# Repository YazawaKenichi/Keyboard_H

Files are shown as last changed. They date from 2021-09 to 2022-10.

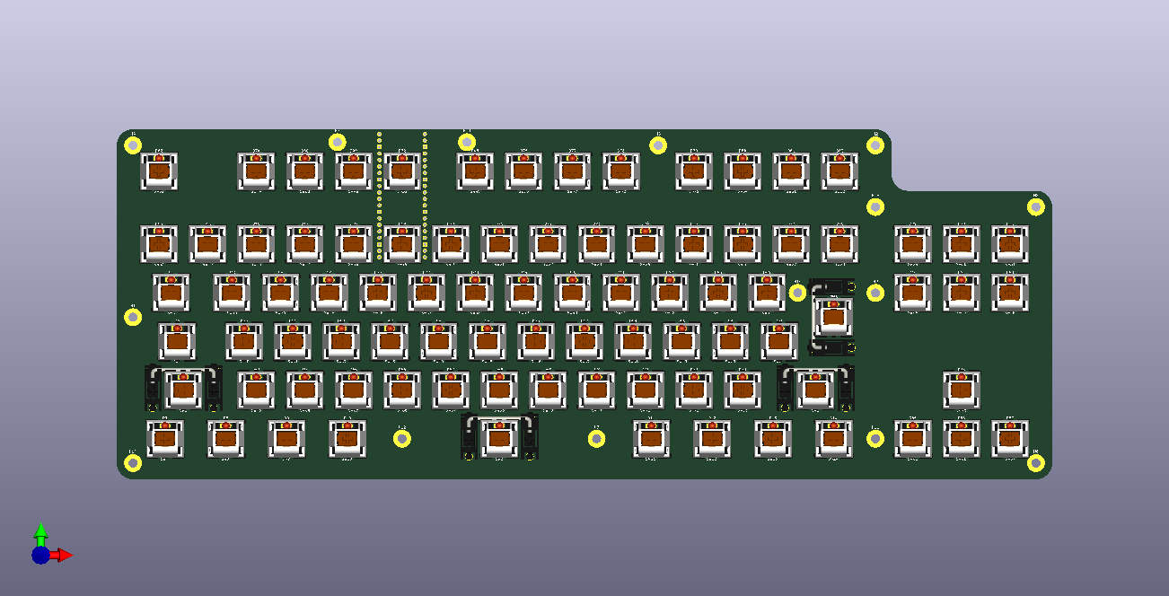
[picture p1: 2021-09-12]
pcb/3D_model/png/keyboard_h.png

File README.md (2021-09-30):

# Keyboard_H
This is My First Keyboard Project.

#### 基板とシャーシのデータの完全形
これらのデータで発注・加工する。

#### 自作キーボードの設計
このリポジトリは自作キーボードのためのリポジトリ。
ただしハードウェア設計に関するファイルのみ。うｐ主のインフラの事情的に、ハードは Windows ソフトは Ubuntu で開発することになってしまったので、ハードとソフトでリポジトリを分けた。
統合してぇなぁ...

### 以下全部自己満メモ！自分用れどめ！

##### LED の点灯回路について考える
- USB バスパワー:5V 500mA
- Raspberry Pi Pico の GPIO のパワー
- Raspberry Pi Pico のピンによる電気特性は [RP2040 のデータシート](https://datasheets.raspberrypi.org/rp2040/rp2040-datasheet.pdf) 『5.2.3. Pin Specifications』を参照
- .
- キーボード全体で 300mA になるようにしたい。
- USB 5V だが、実際 500 mA くらい使用すると 4.8V くらいに下がってしまうので、USB デバイスはそうならないように余裕を持たせて設計する。
- GPIO で FET のゲートを制御し、Vbus からの電力を供給する。
- LED と制限抵抗は必ず一つにまとめる。
- .
- 謎があって、USB から電力を入手するとしても、87 個の LED を並列に点灯させようとすると、一つの 抵抗 + LED に流せる電流は最大でも 300 mA / 87 個 ≒ 3.4 mA となってちょっと弱すぎじゃね？って感じがしてしまう。これじゃあ LED 点灯できないじゃん...
- .
- LED のデータシート？これ何？
- output current 出力の最大値 MAX 100 mA
- current limit 制限電流 MIN 150 mA TYP 350 mA MAX 450 mA
- .
- LED の設定
- 一つの LED に電流制限可変抵抗と LED を直列に繋いだ回路において、デューティー比 100% という条件で以下の状態を記録。
- 電源電圧 5 V
- 抵抗降下電圧 1.692 V
- LED 電圧 3.17 V
- 電流 19.30 mA
- 抵抗値 84.5 Ω
- ※小数点以下一桁目より下は当てにならないかも... 0.1 レベルなら当てになるかも。
- 上記が丁度よい輝度になっている。
- .
- 参考までに、電源電圧 3.3 V の時の値も記録しておく。
- 抵抗降下電圧 0.267 V
- LED 電圧 3.03 V
- 電流 10.58 mA
- 抵抗値 21.2 Ω
- ※小数点以下一桁目より下はry
- .
- ついでのついでに参考として、データシートの値を記録しておく。
- デューティー比 100% 電流値  30 mA
- デューティー比 10 % 電流値 100 mA
- 20 mA の時の LED 電圧降下 3.1 V
- .
- 疑問点
- PWM 制御すれば、デューティー比 100 % の時よりも大きな電流を流せるということはわかるけど、推奨デューティー比が 1/10 とかになってて、結局欲しい輝度に届かなくなったりしないのかな？
- Arduino でいいから実験してみると良いかもしれない。
- .
- FET + PWM で実験してみた。
- Nch MOSFET 2N7000 で実験したので、回路的にはローサイド駆動。
- 電流制限抵抗 45Ω PWM: 20ms(50Hz) 100% において、以下を記録。
- 電流 30 mA LED 降下電圧 3.5 V 抵抗降下電圧 1.46 V 但し、100% では僅かに発熱したため、100% 以下での駆動を推奨する。
- .
- なんかもうぐちゃぐちゃしてきたから、いっそのこと実験して特性曲線を自分でプロットすればいいんじゃないかと思って、特性曲線を描いてみた。いや、厳密には点を打っていっただけなんだけど...
- そのスプレッドシートが[こちら](https://docs.google.com/spreadsheets/d/14N7y58BiVdMig64xLq-WeDRAnExjTIeJXDbpEm-JDAk/edit?usp=sharing)
- .
- PWM 制御について参考にしたサイトと数式（自作）
- [PWM について考える基礎](https://www.sist.ac.jp/club/mcf/Umeta_lecture/PWM.html)
- [上記サイト内で出てくる数式](https://www.geogebra.org/m/sed2b5tw) y が電力 x が電流 r が制限抵抗 v が電源電圧。回路は 電源-抵抗-対象素子-GND
- .
- いろいろ考えたけど、USB 電源である以上、最大 500 mA で、しかも余裕を持たせないといけないから 300 mA にしないといけないことも考慮して、一つの 抵抗-LED に流せる電流を考えたら、3.5 mA が限界なわけで、結局 3.5 mA 流すことになるならそれで考えたら良いのではないかという結論に至った。
- Vbus-可変抵抗-LED-[D]NchMOSFET(ON)-[S]GND[G]330Ωカーボン抵抗-3V3PWM の回路において、PWM 100% かつ LED 電流 3.5 の時、630Ω の電流制限抵抗がいい感じ。

##### FET のゲート抵抗について考える
- ゲート抵抗が無いと FET が ON になったときにショートしてしまう。よってゲート抵抗は必要。
- ではゲート抵抗はどのくらいが良いのか。実は計算する方法がある。
- R_G = V_in / I_G ∩ I_G = Q_g / t で求めることができる。
|記号|意味|
|---|---|
|R_G|ゲート抵抗|
|V_in|入力電圧|
|I_G|ゲート電流|
|Q_g|ゲート入力電荷量|
|t|ゲート立ち上がり時間|
- ここで、入力電圧はゲート抵抗への入力電圧であり、ゲート抵抗を超えた時のゲート電圧とは違う。（つまりゲート抵抗で電圧降下する前の電圧ということ）
- ゲート入力電荷量は、使用する FET のデータシートに記載されている。
- 2N7002 のデータシート見てみたけど、書いてない...今回は 100R でいいんじゃね？

##### 教わったこと
- LED のみを安直に並列に接続してはいけない。一つの LED に対して一つの電流制限抵抗が必要となる。よって LED を並列に接続したいときは電流制限抵抗 + LED で一つの素子として考えたほうがいいかもしれない。
- USB の電力は 5V 500 mA である。しかし、デバイスが 500 mA 近く流れそうになると実際は 5 V より少し小さい値に低下してしまう。これを防ぐためにデバイスに流れる電流は 300 mA 程度とし、余裕を持たせたほうが良い。
- FET のゲート抵抗は計算できる。
- FET の G-S 間には 10kR の抵抗をつなぐとよいことを知った。これは MOSFET が OFF の時確実にゲートを OFF にする目的。抵抗が無いと、G-S 間の疑似コンデンサに電荷がたまった状態で、電位は 0V にならず、浮遊状態となり、基準電位を失ってしまう。結果的にゲートの電位が不安定になり FET を ON にしていないにも関わらず勝手に ON になってしまうことが起きてしまう。
- USB 端子に直接つながっている Vbus 端子には、コンデンサがあるとよい。USB 機器のコードは長く、電圧が降下してしまうので、それを防ぐ意味でコンデンサを Vbus GND 間に取り付ける。ただし今回は PWM 制御することを考えるので、電気容量についても注意する必要がある。井口先輩は考えた末に「勘だけど 20 ~ 47 uF」と言っていた。
- ベタグランドはただやたらめったら面積を広くすればよいというものではなく、ベタグランドがアンテナになってしまうときは、敢えて面積を小さくしてでもベタ GND を除去する必要がある。どうしても除去したくない場合は、裏面のベタグランドにビアを繋ぐことで回避できる。
- 配線幅は電流に応じて変更したほうが良い。というかしろ。

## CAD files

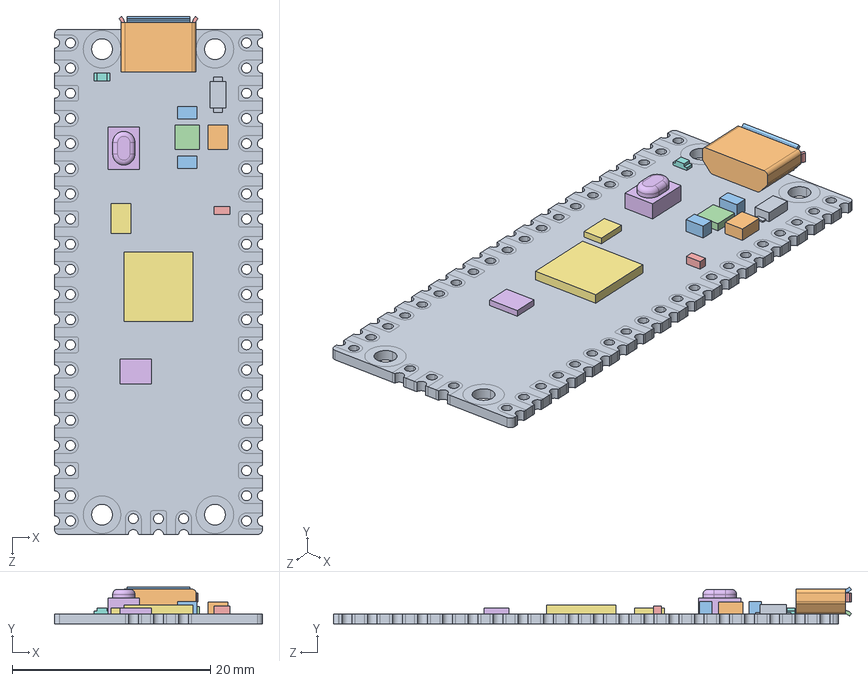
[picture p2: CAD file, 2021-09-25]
pcb/3D_model/step/Pico-R3-step/Pico-R3.step
21.0 x 3.73 x 52.3 mm
PICO_REF_BOARD.STEP
PICO_REF_USB.STEP
PICO_REF_SWITCH.STEP
PICO_REF_MICROCONTROLLER.STEP
PICO_REF_LED.STEP
PICO_REF_ONSEMI.STEP
PICO_BOURNS.STEP
PICO_MURATA.STEP x 2
PICO_RICHTEK.STEP
PICO_DIODES.STEP
PICO_AEL.STEP
PICO_WINBOND.STEP

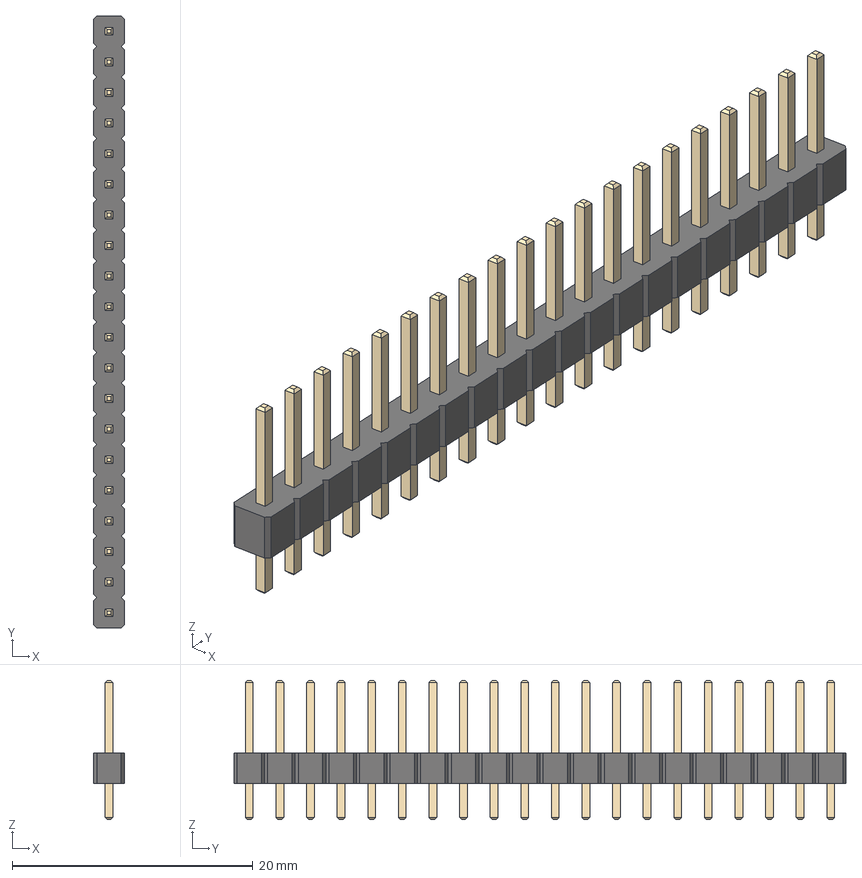
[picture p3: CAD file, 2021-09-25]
pcb/3D_model/step/PinHeader_1x20_P2.54mm_Vertical.step
2.54 x 50.8 x 11.5 mm

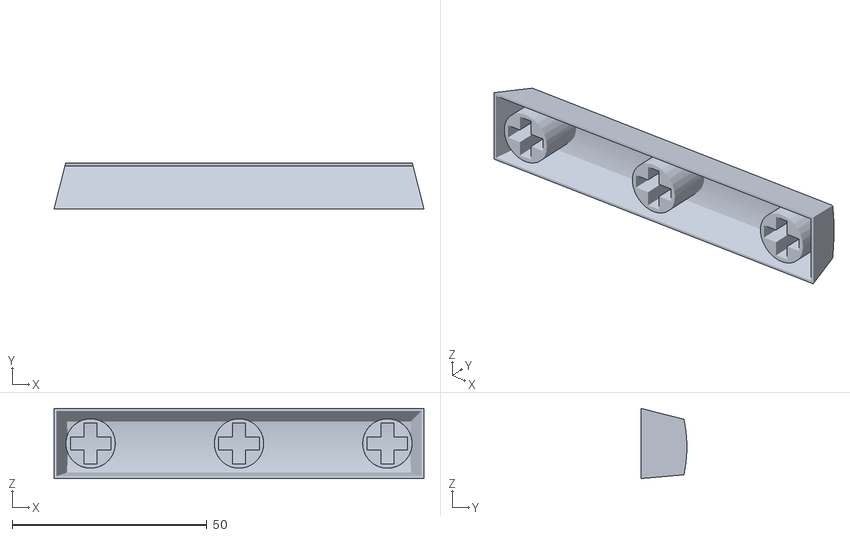
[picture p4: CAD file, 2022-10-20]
chassis/2022/SpaceKeyCap.stl
95.0 x 11.7 x 18.0

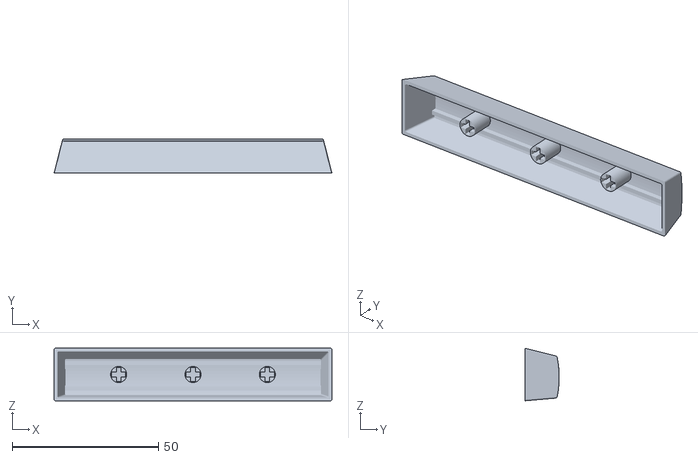
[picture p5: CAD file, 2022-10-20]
chassis/2022/SpaceKeyCap_v8.stl
95.0 x 11.8 x 18.0

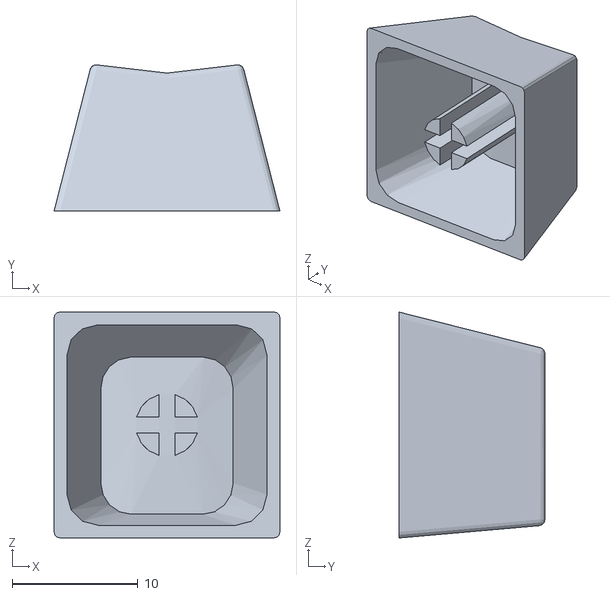
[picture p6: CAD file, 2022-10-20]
chassis/2022/now.stl
18.0 x 11.7 x 18.0

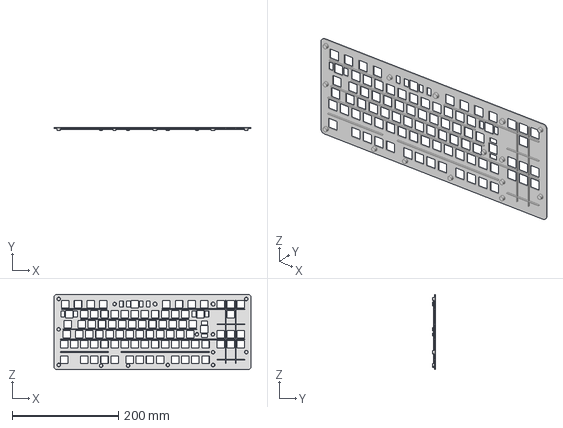
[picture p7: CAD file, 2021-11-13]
chassis/2022/Plate.step
371.5 x 5.00 x 142.2 mm

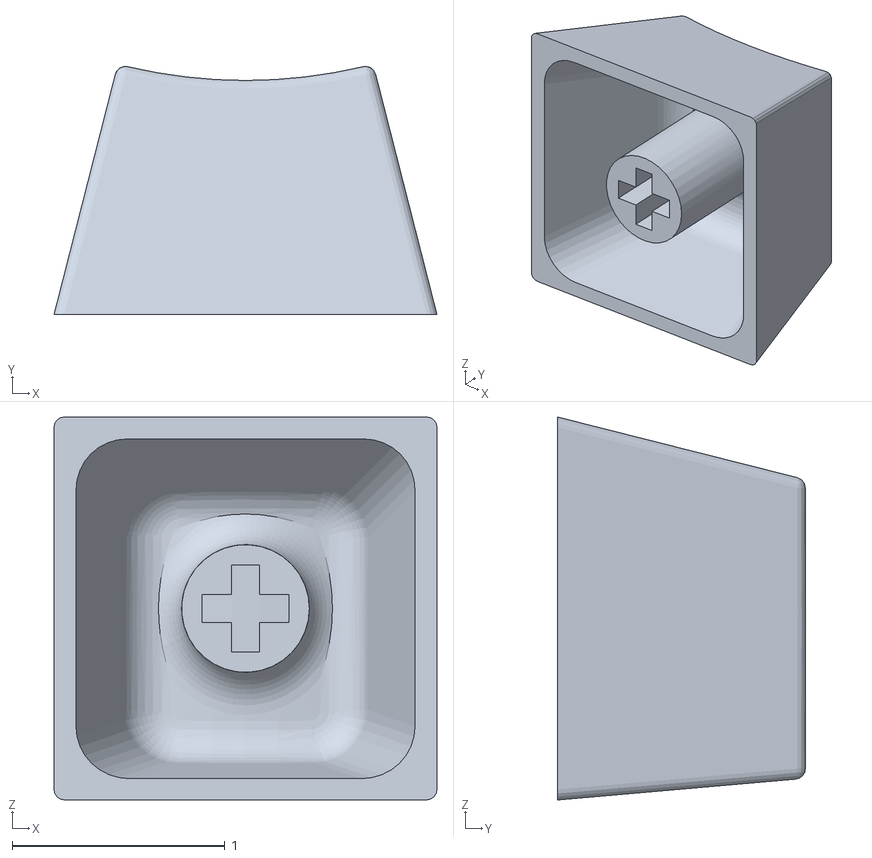
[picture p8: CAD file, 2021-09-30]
chassis/2022/Cap Plane.stl
1.80 x 1.17 x 1.80

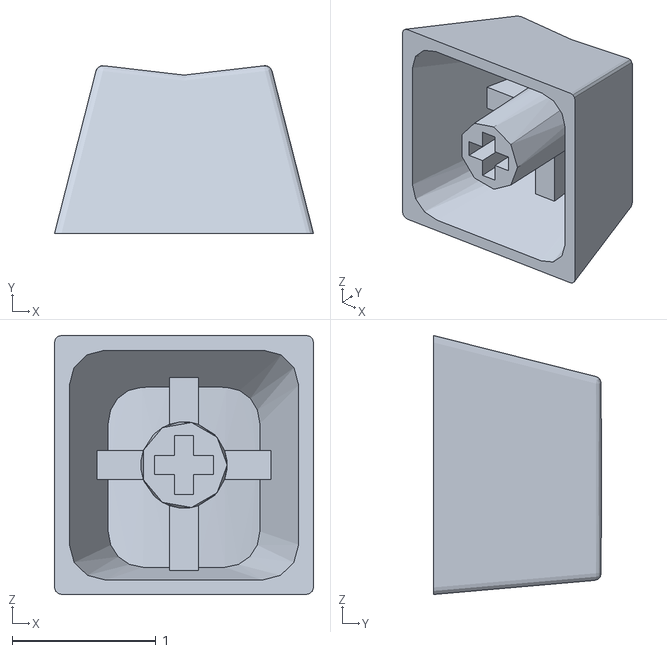
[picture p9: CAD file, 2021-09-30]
chassis/2022/Cap Support.stl
1.80 x 1.17 x 1.80

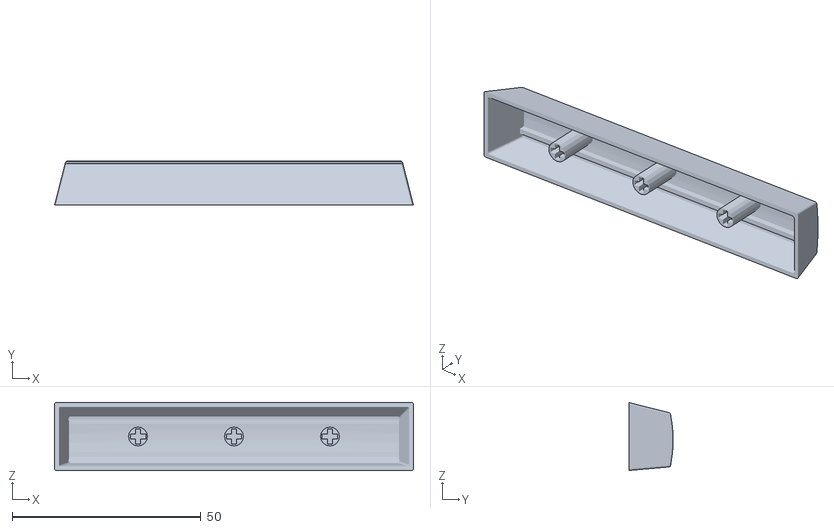
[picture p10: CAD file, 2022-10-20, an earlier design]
chassis/2022/SpaceKeyCap_v4.stl
95.0 x 11.8 x 18.0

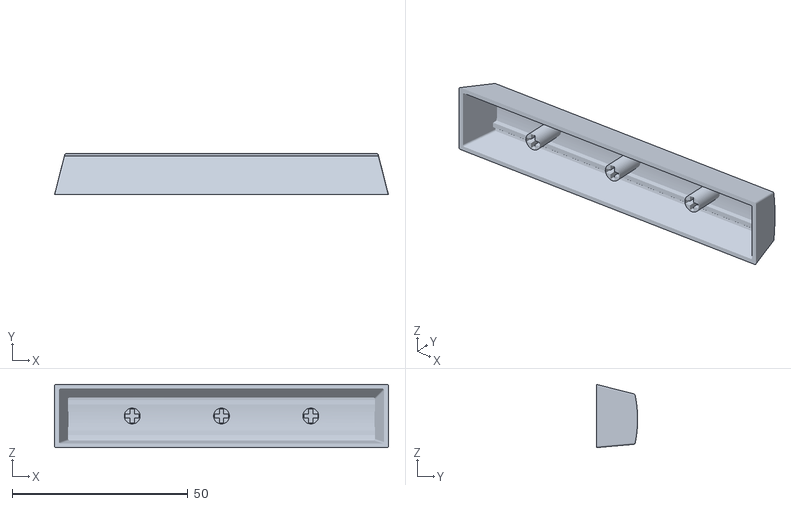
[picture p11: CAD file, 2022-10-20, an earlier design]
chassis/2022/SpaceKeyCap_v9_Stereolithography.stl
95.0 x 11.8 x 18.0

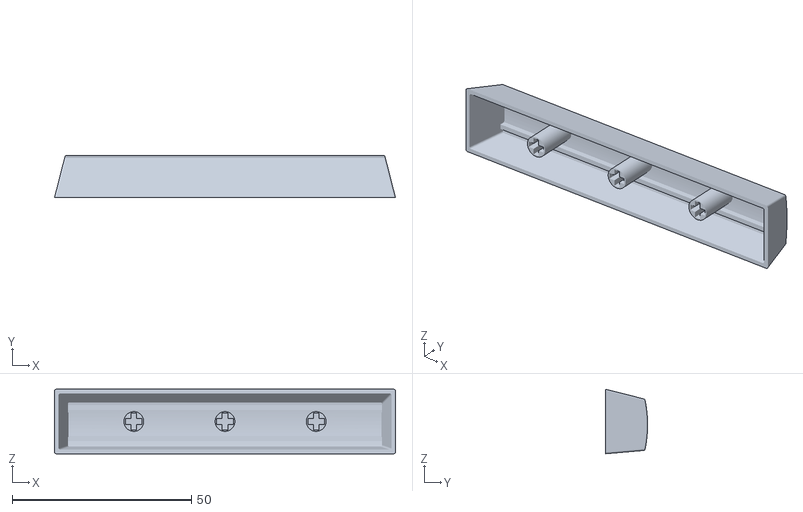
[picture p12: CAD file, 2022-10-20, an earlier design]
chassis/2022/SpaceKeyCap_v7.stl
95.0 x 11.8 x 18.0

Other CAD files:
chassis/2022/SpaceKeyCap_v10_Stereolithography.stl
chassis/2022/SpaceKeyCap_v5.stl
chassis/2022/SpaceKeyCap_v6.stl
chassis/2022/SpaceKeyCap_v3.stl
chassis/2022/SpaceKeyCap_v2.stl
chassis/2020/Base.x_t
chassis/2020/Plate.x_t
chassis/2022/Assembly.iam
chassis/2022/Base.idw
chassis/2022/Base.ipt
chassis/2022/Cap.ipt
chassis/2022/OldVersions/Assembly.0016.iam
chassis/2022/OldVersions/Base.0001.idw
chassis/2022/OldVersions/Base.0042.ipt
chassis/2022/OldVersions/Cap.0009.ipt
chassis/2022/OldVersions/Plate.0004.idw
chassis/2022/OldVersions/Plate.0043.ipt
chassis/2022/OldVersions/SpaceKeyCap.0002.idw
chassis/2022/OldVersions/SpaceKeyCap.0009.ipt
chassis/2022/OldVersions/stabbar_u5.0001.ipt
chassis/2022/Plate.idw
chassis/2022/Plate.ipt
chassis/2022/SpaceKeyCap.idw
chassis/2022/SpaceKeyCap.ipt
chassis/2022/stabbar_u5.ipt
chassis/Plate.ipt
pcb/3D_model/step/COMPOUND.ipt
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

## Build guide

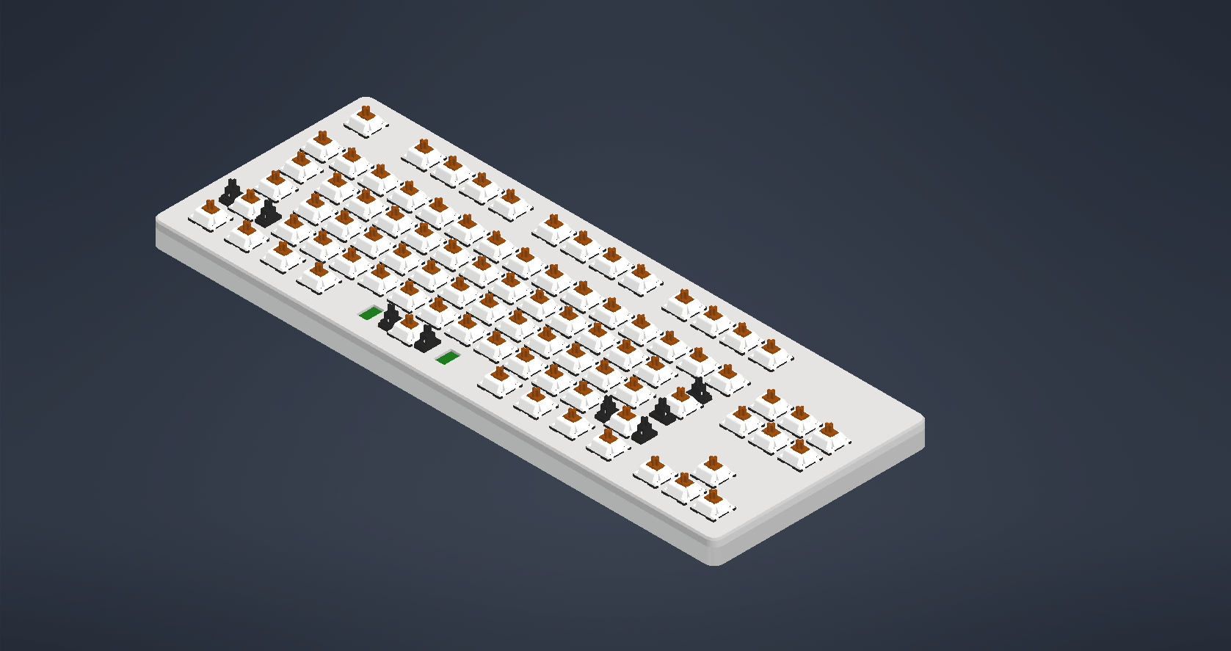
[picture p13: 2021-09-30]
chassis/2022/Assembly.png

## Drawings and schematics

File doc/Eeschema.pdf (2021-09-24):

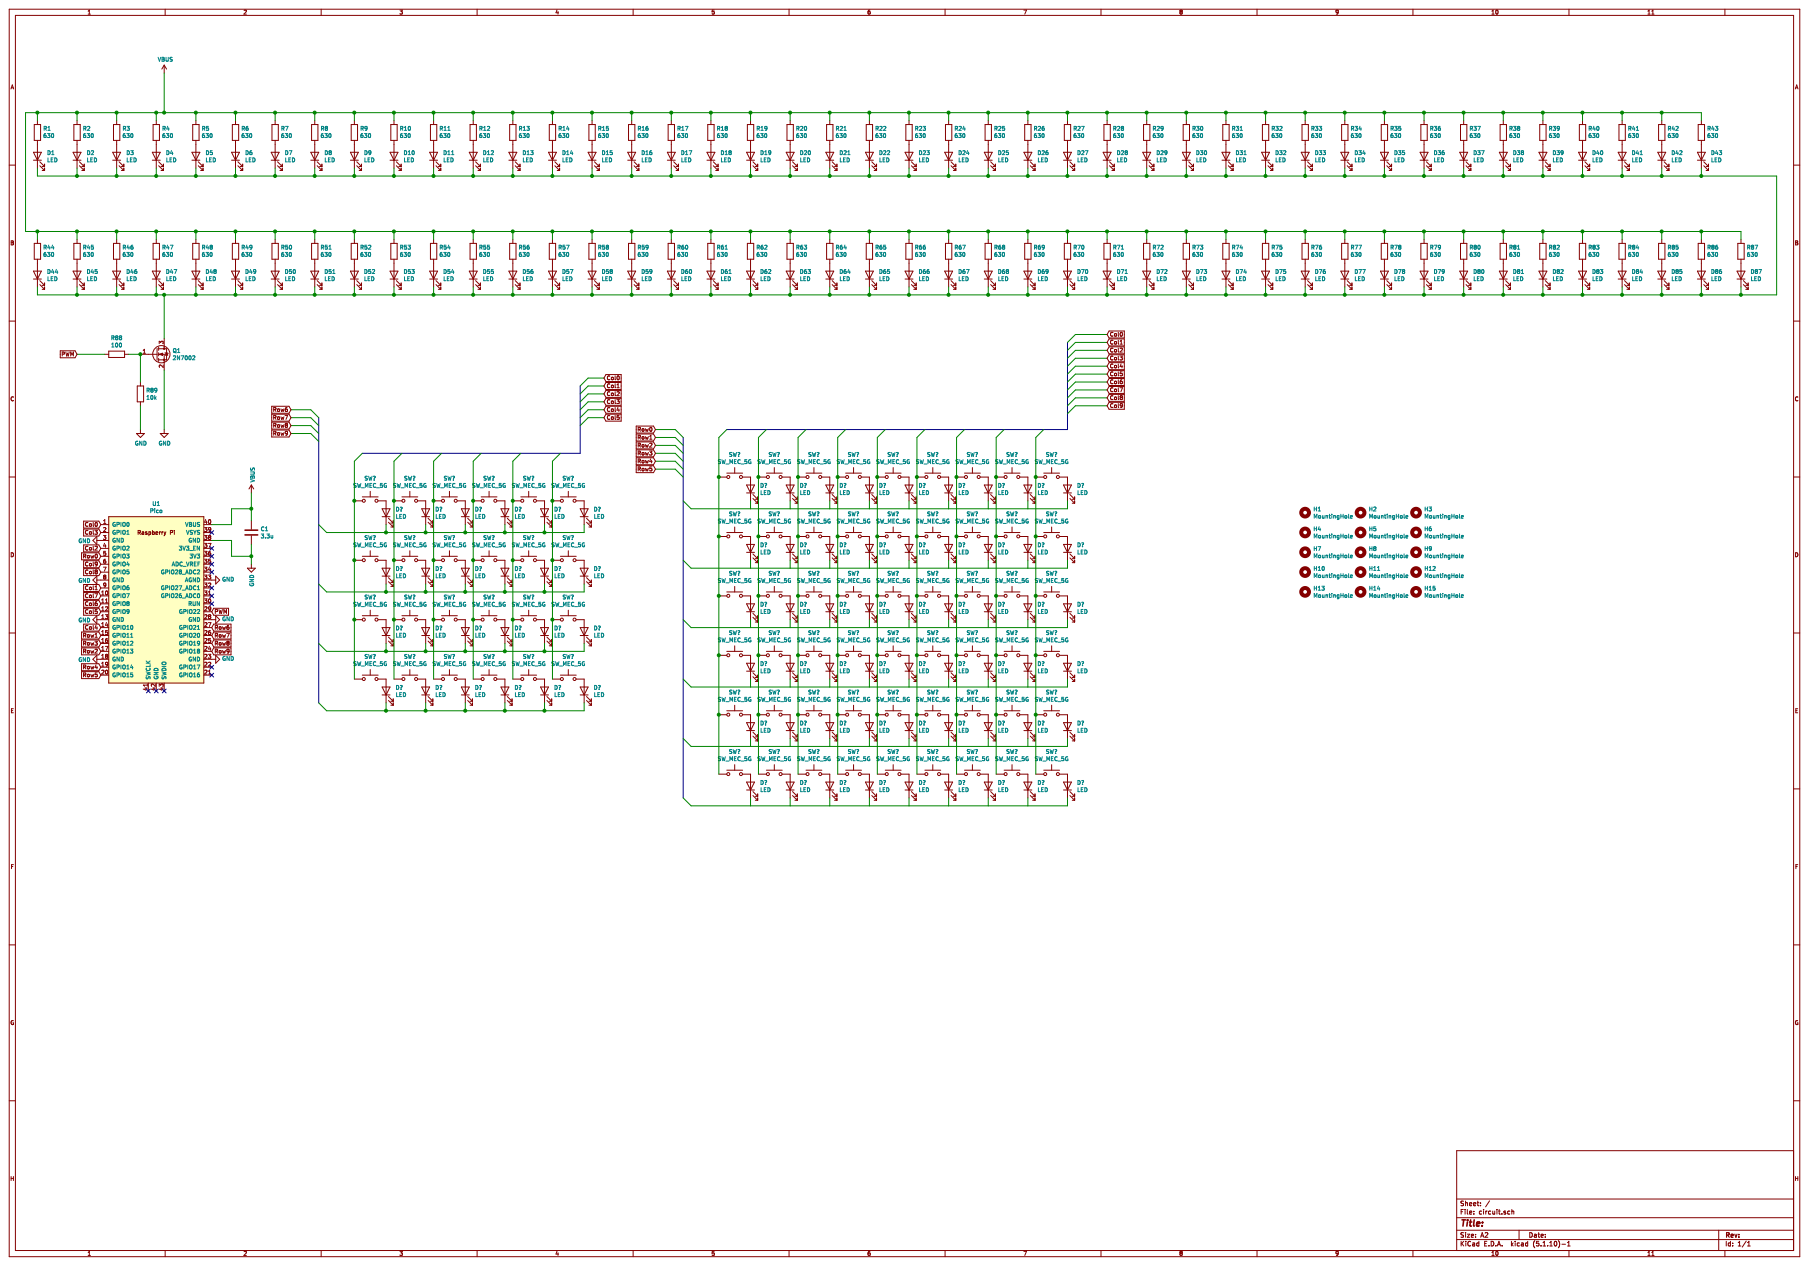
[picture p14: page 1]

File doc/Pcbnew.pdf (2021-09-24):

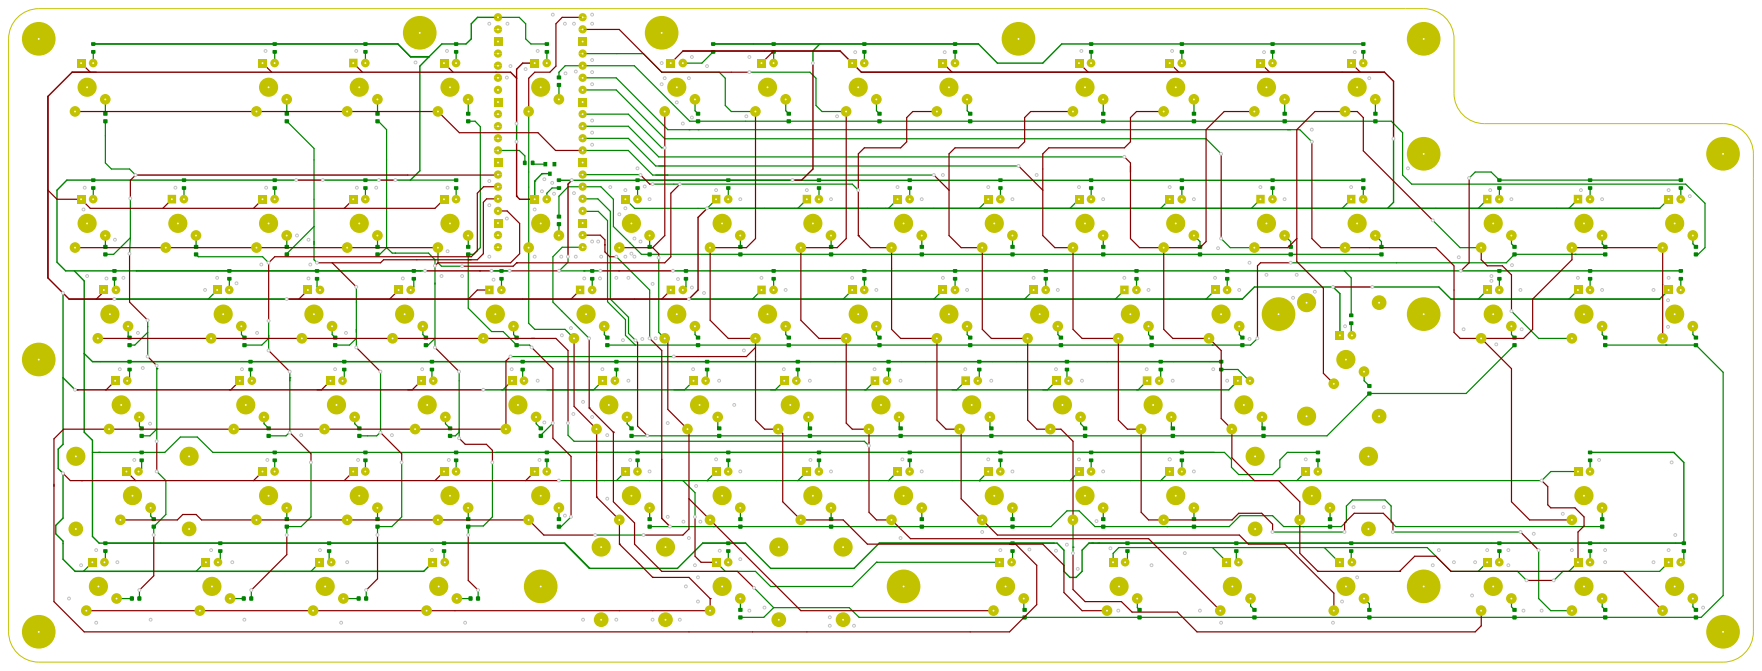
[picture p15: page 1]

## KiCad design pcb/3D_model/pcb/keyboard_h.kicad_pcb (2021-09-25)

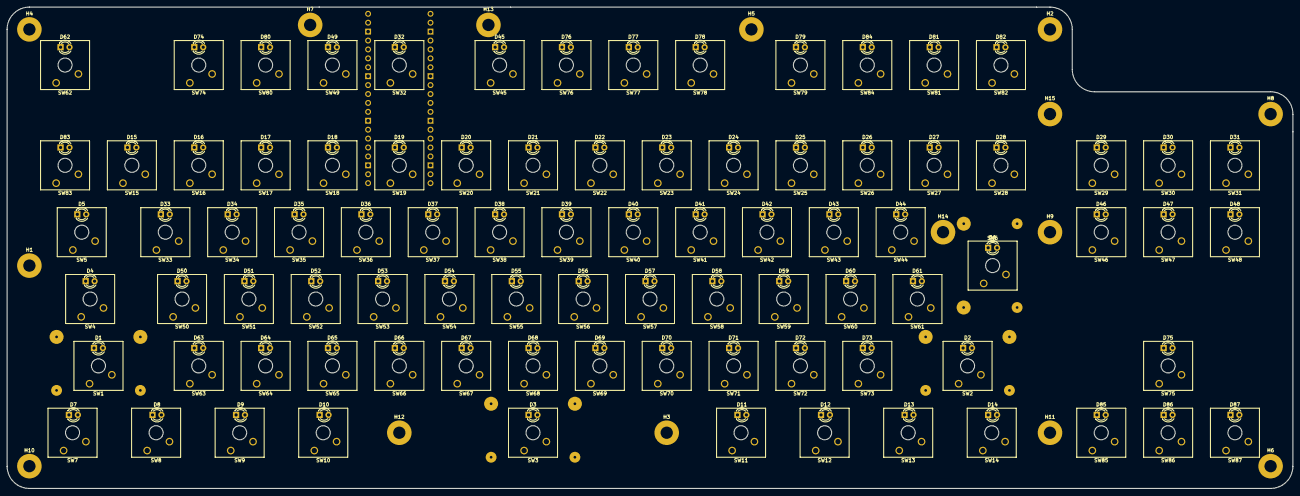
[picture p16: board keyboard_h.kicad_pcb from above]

Board: 2 copper layers, 366.4 x 137.2 mm, 190 parts (1 on the bottom side), 87 nets, no tracks yet.

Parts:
D1, D2, D3, D4, D5, D6, D7, D8, D9, D10, D11, D12, D13, D14, D15, D16, D17, D18, D19, D20, D21, D22, D23, D24, D25, D26, D27, D28, D29, D30, D31, D32, D33, D34, D35, D36, D37, D38, D39, D40, D41, D42, D43, D44, D45, D46, D47, D48, D49, D50, D51, D52, D53, D54, D55, D56, D57, D58, D59, D60, D61, D62, D63, D64, D65, D66, D67, D68, D69, D70, D71, D72, D73, D74, D75, D76, D77, D78, D79, D80, D81, D82, D83, D84, D85, D86, D87: LED; LED_D3.0mm
H1, H2, H3, H4, H5, H6, H7, H8, H9, H10, H11, H12, H13, H14, H15: MountingHole; MountingHole_3.5mm_Pad
SW1, SW2, SW3: SW_MEC_5G; SW_Cherry_MX_2.00u_Plate
SW4: SW_MEC_5G; SW_Cherry_MX_1.75u_Plate
SW5: SW_MEC_5G; SW_Cherry_MX_1.50u_Plate
SW6: SW_MEC_5G; SW_Cherry_MX_ISOEnter_Plate
SW7, SW8, SW9, SW10, SW11, SW12, SW13, SW14: SW_MEC_5G; SW_Cherry_MX_1.25u_Plate
SW15, SW16, SW17, SW18, SW19, SW20, SW21, SW22, SW23, SW24, SW25, SW26, SW27, SW28, SW29, SW30, SW31, SW32, SW33, SW34, SW35, SW36, SW37, SW38, SW39, SW40, SW41, SW42, SW43, SW44, SW45, SW46, SW47, SW48, SW49, SW50, SW51, SW52, SW53, SW54, SW55, SW56, SW57, SW58, SW59, SW60, SW61, SW62, SW63, SW64, SW65, SW66, SW67, SW68, SW69, SW70, SW71, SW72, SW73, SW74, SW75, SW76, SW77, SW78, SW79, SW80, SW81, SW82, SW83, SW84, SW85, SW86, SW87: SW_MEC_5G; SW_Cherry_MX_1.00u_Plate
U1: Pico; RPi_Pico_SMD_TH

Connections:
unnamed: SW1.1, SW1.2
unnamed: SW2.1, SW2.2
unnamed: SW3.1, SW3.2
unnamed: SW4.1, SW4.2
unnamed: SW5.1, SW5.2
unnamed: SW6.1, SW6.2
unnamed: SW7.1, SW7.2
unnamed: SW8.1, SW8.2
unnamed: SW9.1, SW9.2
unnamed: SW10.1, SW10.2
unnamed: SW11.1, SW11.2
unnamed: SW12.1, SW12.2
unnamed: SW13.1, SW13.2
unnamed: SW14.1, SW14.2
unnamed: SW15.1, SW15.2
unnamed: SW16.1, SW16.2
unnamed: SW17.1, SW17.2
unnamed: SW18.1, SW18.2
unnamed: SW19.1, SW19.2
unnamed: SW20.1, SW20.2
unnamed: SW21.1, SW21.2
unnamed: SW22.1, SW22.2
unnamed: SW23.1, SW23.2
unnamed: SW24.1, SW24.2
unnamed: SW25.1, SW25.2
unnamed: SW26.1, SW26.2
unnamed: SW27.1, SW27.2
unnamed: SW28.1, SW28.2
unnamed: SW29.1, SW29.2
unnamed: SW30.1, SW30.2
unnamed: SW31.1, SW31.2
unnamed: SW32.1, SW32.2
unnamed: SW33.1, SW33.2
unnamed: SW34.1, SW34.2
unnamed: SW35.1, SW35.2
unnamed: SW36.1, SW36.2
unnamed: SW37.1, SW37.2
unnamed: SW38.1, SW38.2
unnamed: SW39.1, SW39.2
unnamed: SW40.1, SW40.2
unnamed: SW41.1, SW41.2
unnamed: SW42.1, SW42.2
unnamed: SW43.1, SW43.2
unnamed: SW44.1, SW44.2
unnamed: SW45.1, SW45.2
unnamed: SW46.1, SW46.2
unnamed: SW47.1, SW47.2
unnamed: SW48.1, SW48.2
unnamed: SW49.1, SW49.2
unnamed: SW50.1, SW50.2
unnamed: SW51.1, SW51.2
unnamed: SW52.1, SW52.2
unnamed: SW53.1, SW53.2
unnamed: SW54.1, SW54.2
unnamed: SW55.1, SW55.2
unnamed: SW56.1, SW56.2
unnamed: SW57.1, SW57.2
unnamed: SW58.1, SW58.2
unnamed: SW59.1, SW59.2
unnamed: SW60.1, SW60.2
unnamed: SW61.1, SW61.2
unnamed: SW62.1, SW62.2
unnamed: SW63.1, SW63.2
unnamed: SW64.1, SW64.2
unnamed: SW65.1, SW65.2
unnamed: SW66.1, SW66.2
unnamed: SW67.1, SW67.2
unnamed: SW68.1, SW68.2
unnamed: SW69.1, SW69.2
unnamed: SW70.1, SW70.2
unnamed: SW71.1, SW71.2
unnamed: SW72.1, SW72.2
unnamed: SW73.1, SW73.2
unnamed: SW74.1, SW74.2
unnamed: SW75.1, SW75.2
unnamed: SW76.1, SW76.2
unnamed: SW77.1, SW77.2
unnamed: SW78.1, SW78.2
unnamed: SW79.1, SW79.2
unnamed: SW80.1, SW80.2
unnamed: SW81.1, SW81.2
unnamed: SW82.1, SW82.2
unnamed: SW83.1, SW83.2
unnamed: SW84.1, SW84.2
unnamed: SW85.1, SW85.2
unnamed: SW86.1, SW86.2
unnamed: SW87.1, SW87.2

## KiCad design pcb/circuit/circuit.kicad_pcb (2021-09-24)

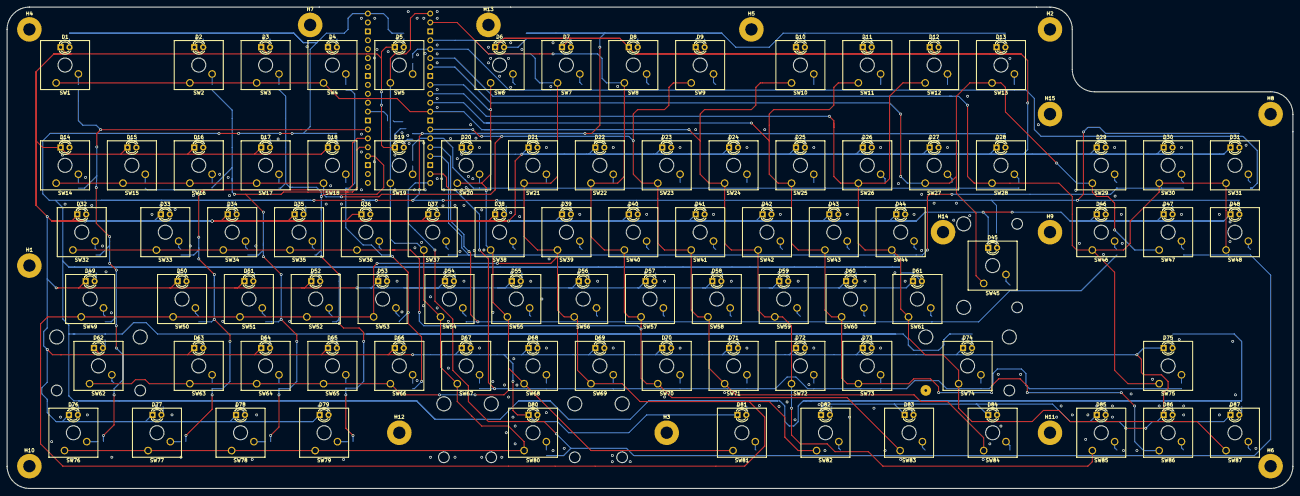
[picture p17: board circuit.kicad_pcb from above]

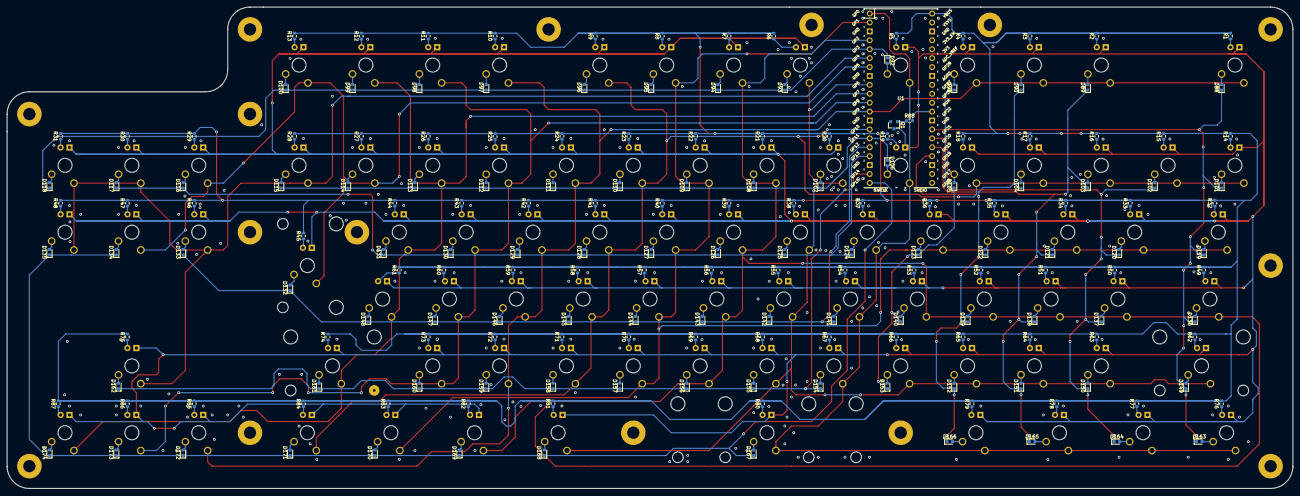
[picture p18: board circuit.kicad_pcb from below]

Board: 2 copper layers, 366.4 x 137.2 mm, 366 parts (177 on the bottom side), 200 nets.

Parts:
D1, D2, D3, D4, D5, D6, D7, D8, D9, D10, D11, D12, D13, D14, D15, D16, D17, D18, D19, D20, D21, D22, D23, D24, D25, D26, D27, D28, D29, D30, D31, D32, D33, D34, D35, D36, D37, D38, D39, D40, D41, D42, D43, D44, D45, D46, D47, D48, D49, D50, D51, D52, D53, D54, D55, D56, D57, D58, D59, D60, D61, D62, D63, D64, D65, D66, D67, D68, D69, D70, D71, D72, D73, D74, D75, D76, D77, D78, D79, D80, D81, D82, D83, D84, D85, D86, D87: LED; LED_D3.0mm
D88, D89, D90, D91, D92, D93, D94, D95, D96, D97, D98, D99, D100, D101, D102, D103, D104, D105, D106, D107, D108, D109, D110, D111, D112, D113, D114, D115, D116, D117, D118, D119, D120, D121, D122, D123, D124, D125, D126, D127, D128, D129, D130, D131, D132, D133, D134, D135, D136, D137, D138, D139, D140, D141, D142, D143, D144, D145, D146, D147, D148, D149, D150, D151, D152, D153, D154, D155, D156, D157, D158, D159, D160, D161, D162, D163, D164, D165, D166, D167, D168, D169, D170, D171, D172, D173, D174: 1N4148; LED_0603_1608Metric
H1, H2, H3, H4, H5, H6, H7, H8, H9, H10, H11, H12, H13, H14, H15: MountingHole; MountingHole_3.5mm_Pad
Q1: 2N7002; SOT-23
R1, R2, R3, R4, R5, R6, R7, R8, R9, R10, R11, R12, R13, R14, R15, R16, R17, R18, R19, R20, R21, R22, R23, R24, R25, R26, R27, R28, R29, R30, R31, R32, R33, R34, R35, R36, R37, R38, R39, R40, R41, R42, R43, R44, R45, R46, R47, R48, R49, R50, R51, R52, R53, R54, R55, R56, R57, R58, R59, R60, R61, R62, R63, R64, R65, R66, R67, R68, R69, R70, R71, R72, R73, R74, R75, R76, R77, R78, R79, R80, R81, R82, R83, R84, R85, R86, R87: 630; R_0603_1608Metric
R88: 100; R_0603_1608Metric
SW1, SW2, SW3, SW4, SW5, SW6, SW7, SW8, SW9, SW10, SW11, SW12, SW13, SW14, SW15, SW16, SW17, SW18, SW19, SW20, SW21, SW22, SW23, SW24, SW25, SW26, SW27, SW28, SW29, SW30, SW31, SW33, SW34, SW35, SW36, SW37, SW38, SW39, SW40, SW41, SW42, SW43, SW44, SW46, SW47, SW48, SW50, SW51, SW52, SW53, SW54, SW55, SW56, SW57, SW58, SW59, SW60, SW61, SW63, SW64, SW65, SW66, SW67, SW68, SW69, SW70, SW71, SW72, SW73, SW75, SW85, SW86, SW87: CherryMX; SW_Cherry_MX_1.00u_PCB
SW32, SW76, SW77, SW78, SW79, SW81, SW82, SW83, SW84: CherryMX; SW_Cherry_MX_1.25u_PCB
SW45: CherryMX; SW_Cherry_MX_ISOEnter_PCB
SW49: CherryMX; SW_Cherry_MX_1.50u_PCB
SW62, SW74: CherryMX; SW_Cherry_MX_1.75u_PCB
SW80: CherryMX; SW_Cherry_MX_2.00u_PCB
U1: Pico; RPi_Pico_SMD_TH

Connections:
Col0: SW5.1, SW19.1, SW37.1, SW54.1, SW67.1, SW76.1, SW77.1, SW78.1, SW79.1, SW80.1, U1.1
Col1: SW6.1, SW20.1, SW38.1, SW55.1, SW62.1, SW63.1, SW64.1, SW65.1, SW66.1, SW68.1, SW81.1, U1.9
Col2: SW7.1, SW21.1, SW39.1, SW49.1, SW50.1, SW51.1, SW52.1, SW53.1, SW56.1, SW69.1, SW82.1, U1.4
Col3: SW8.1, SW22.1, SW32.1, SW33.1, SW34.1, SW35.1, SW36.1, SW40.1, SW57.1, SW70.1, SW83.1, U1.2
Col4: SW9.1, SW14.1, SW15.1, SW16.1, SW17.1, SW18.1, SW23.1, SW41.1, SW58.1, SW71.1, SW84.1, U1.14
Col5: SW1.1, SW2.1, SW3.1, SW4.1, SW10.1, SW24.1, SW42.1, SW59.1, SW72.1, SW85.1, U1.12
Col6: SW11.1, SW25.1, SW43.1, SW60.1, SW73.1, SW86.1, U1.11
Col7: SW12.1, SW26.1, SW44.1, SW61.1, SW74.1, SW87.1, U1.10
Col8: SW13.1, SW27.1, SW29.1, SW45.1, SW47.1, U1.7
Col9: SW28.1, SW30.1, SW31.1, SW46.1, SW48.1, SW75.1, U1.6
GND: Q1.2, U1.3, U1.8, U1.13, U1.18, U1.23, U1.28, U1.33, U1.38
unnamed: D1.1, D2.1, D3.1, D4.1, D5.1, D6.1, D7.1, D8.1, D9.1, D10.1, D11.1, D12.1, D13.1, D14.1, D15.1, D16.1, D17.1, D18.1, D19.1, D20.1, D21.1, D22.1, D23.1, D24.1, D25.1, D26.1, D27.1, D28.1, D29.1, D30.1, D31.1, D32.1, D33.1, D34.1, D35.1, D36.1, D37.1, D38.1, D39.1, D40.1, D41.1, D42.1, D43.1, D44.1, D45.1, D46.1, D47.1, D48.1, D49.1, D50.1, D51.1, D52.1, D53.1, D54.1, D55.1, D56.1, D57.1, D58.1, D59.1, D60.1, D61.1, D62.1, D63.1, D64.1, D65.1, D66.1, D67.1, D68.1, D69.1, D70.1, D71.1, D72.1, D73.1, D74.1, D75.1, D76.1, D77.1, D78.1, D79.1, D80.1, D81.1, D82.1, D83.1, D84.1, D85.1, D86.1, D87.1, Q1.3
unnamed: D1.2, R1.1
unnamed: D2.2, R2.1
unnamed: D3.2, R3.1
unnamed: D4.2, R4.1
unnamed: D5.2, R5.1
unnamed: D6.2, R6.1
unnamed: D7.2, R7.1
unnamed: D8.2, R8.1
unnamed: D9.2, R9.1
unnamed: D10.2, R10.1
unnamed: D11.2, R11.1
unnamed: D12.2, R12.1
unnamed: D13.2, R13.1
unnamed: D14.2, R14.1
unnamed: D15.2, R15.1
unnamed: D16.2, R16.1
unnamed: D17.2, R17.1
unnamed: D18.2, R18.1
unnamed: D19.2, R19.1
unnamed: D20.2, R20.1
unnamed: D21.2, R21.1
unnamed: D22.2, R22.1
unnamed: D23.2, R23.1
unnamed: D24.2, R24.1
unnamed: D25.2, R25.1
unnamed: D26.2, R26.1
unnamed: D27.2, R27.1
unnamed: D28.2, R28.1
unnamed: D29.2, R29.1
unnamed: D30.2, R30.1
unnamed: D31.2, R31.1
unnamed: D32.2, R32.1
unnamed: D33.2, R33.1
unnamed: D34.2, R34.1
unnamed: D35.2, R35.1
unnamed: D36.2, R36.1
unnamed: D37.2, R37.1
unnamed: D38.2, R38.1
unnamed: D39.2, R39.1
unnamed: D40.2, R40.1
unnamed: D41.2, R41.1
unnamed: D42.2, R42.1
unnamed: D43.2, R43.1
unnamed: D44.2, R44.1
unnamed: D45.2, R45.1
unnamed: D46.2, R46.1
unnamed: D47.2, R47.1
unnamed: D48.2, R48.1
unnamed: D49.2, R49.1
unnamed: D50.2, R50.1
unnamed: D51.2, R51.1
unnamed: D52.2, R52.1
unnamed: D53.2, R53.1
unnamed: D54.2, R54.1
unnamed: D55.2, R55.1
unnamed: D56.2, R56.1
unnamed: D57.2, R57.1
unnamed: D58.2, R58.1
unnamed: D59.2, R59.1
unnamed: D60.2, R60.1
unnamed: D61.2, R61.1
unnamed: D62.2, R62.1
unnamed: D63.2, R63.1
unnamed: D64.2, R64.1
unnamed: D65.2, R65.1
unnamed: D66.2, R66.1
unnamed: D67.2, R67.1
unnamed: D68.2, R68.1
unnamed: D69.2, R69.1
unnamed: D70.2, R70.1
unnamed: D71.2, R71.1
unnamed: D72.2, R72.1
unnamed: D73.2, R73.1
unnamed: D74.2, R74.1
unnamed: D75.2, R75.1
unnamed: D76.2, R76.1
unnamed: D77.2, R77.1
unnamed: D78.2, R78.1
unnamed: D79.2, R79.1
unnamed: D80.2, R80.1
unnamed: D81.2, R81.1
unnamed: D82.2, R82.1
unnamed: D83.2, R83.1
unnamed: D84.2, R84.1
unnamed: D85.2, R85.1
unnamed: D86.2, R86.1
unnamed: D87.2, R87.1
unnamed: D88.2, SW1.2
unnamed: D89.2, SW2.2
unnamed: D90.2, SW3.2
unnamed: D91.2, SW4.2
unnamed: D92.2, SW5.2
unnamed: D93.2, SW6.2
unnamed: D94.2, SW7.2
unnamed: D95.2, SW8.2
unnamed: D96.2, SW9.2
unnamed: D97.2, SW10.2
unnamed: D98.2, SW11.2
unnamed: D99.2, SW12.2
unnamed: D100.2, SW13.2
unnamed: D101.2, SW14.2
unnamed: D102.2, SW15.2
unnamed: D103.2, SW16.2
unnamed: D104.2, SW17.2
unnamed: D91.1, D105.1, D123.1, D140.1, D153.1
unnamed: D105.2, SW18.2
unnamed: D106.2, SW19.2
unnamed: D107.2, SW20.2
unnamed: D108.2, SW21.2
unnamed: D109.2, SW22.2
unnamed: D110.2, SW23.2
unnamed: D111.2, SW24.2
unnamed: D112.2, SW25.2
unnamed: D113.2, SW26.2
unnamed: D114.2, SW27.2
unnamed: D115.2, SW28.2
unnamed: D116.2, SW29.2
unnamed: D117.2, SW30.2
unnamed: D118.2, SW31.2
unnamed: D119.2, SW32.2
unnamed: D120.2, SW33.2
unnamed: D121.2, SW34.2
unnamed: D122.2, SW35.2
unnamed: D123.2, SW36.2
unnamed: D124.2, SW37.2
unnamed: D125.2, SW38.2
unnamed: D126.2, SW39.2
unnamed: D127.2, SW40.2
unnamed: D128.2, SW41.2
unnamed: D129.2, SW42.2
unnamed: D130.2, SW43.2
unnamed: D131.2, SW44.2
unnamed: D132.2, SW45.2
unnamed: D133.2, SW46.2
unnamed: D134.2, SW47.2
unnamed: D135.2, SW48.2
unnamed: D136.2, SW49.2
unnamed: D137.2, SW50.2
unnamed: D138.2, SW51.2
unnamed: D139.2, SW52.2
unnamed: D140.2, SW53.2
unnamed: D141.2, SW54.2
unnamed: D142.2, SW55.2
unnamed: D143.2, SW56.2
unnamed: D144.2, SW57.2
unnamed: D145.2, SW58.2
unnamed: D146.2, SW59.2
unnamed: D147.2, SW60.2
unnamed: D148.2, SW61.2
unnamed: D149.2, SW62.2
unnamed: D150.2, SW63.2
unnamed: D151.2, SW64.2
unnamed: D152.2, SW65.2
unnamed: D153.2, SW66.2
unnamed: D154.2, SW67.2
unnamed: D155.2, SW68.2
unnamed: D156.2, SW69.2
unnamed: D157.2, SW70.2
unnamed: D158.2, SW71.2
unnamed: D159.2, SW72.2
unnamed: D160.2, SW73.2
unnamed: D161.2, SW74.2
unnamed: D162.2, SW75.2
unnamed: D163.2, SW76.2
unnamed: D164.2, SW77.2
unnamed: D165.2, SW78.2
unnamed: D166.2, SW79.2
unnamed: D167.2, SW80.2
unnamed: D168.2, SW81.2
unnamed: D169.2, SW82.2
unnamed: D170.2, SW83.2
unnamed: D171.2, SW84.2
unnamed: D172.2, SW85.2
unnamed: D173.2, SW86.2
unnamed: D174.2, SW87.2
unnamed: Q1.1, R88.1
PWM: R88.2, U1.29
Row0: D92.1, D93.1, D94.1, D95.1, D96.1, D97.1, D98.1, D99.1, D100.1, D118.1, U1.5
Row1: D106.1, D107.1, D108.1, D109.1, D110.1, D111.1, D112.1, D113.1, D114.1, D115.1, U1.15
Row2: D116.1, D117.1, D124.1, D125.1, D126.1, D127.1, D128.1, D129.1, D130.1, D131.1, U1.17
Row3: D132.1, D133.1, D141.1, D142.1, D143.1, D144.1, D145.1, D146.1, D147.1, D148.1, U1.16
Row4: D154.1, D155.1, D156.1, D157.1, D158.1, D159.1, D160.1, D161.1, D162.1, U1.19
Row5: D134.1, D135.1, D167.1, D168.1, D169.1, D170.1, D171.1, D172.1, D173.1, D174.1, U1.20
Row6: D88.1, D101.1, D119.1, D136.1, D149.1, D163.1, U1.27
Row7: D102.1, D120.1, D137.1, D150.1, D164.1, U1.26
Row8: D89.1, D103.1, D121.1, D138.1, D151.1, D165.1, U1.25
Row9: D90.1, D104.1, D122.1, D139.1, D152.1, D166.1, U1.24
VBUS: R1.2, R2.2, R3.2, R4.2, R5.2, R6.2, R7.2, R8.2, R9.2, R10.2, R11.2, R12.2, R13.2, R14.2, R15.2, R16.2, R17.2, R18.2, R19.2, R20.2, R21.2, R22.2, R23.2, R24.2, R25.2, R26.2, R27.2, R28.2, R29.2, R30.2, R31.2, R32.2, R33.2, R34.2, R35.2, R36.2, R37.2, R38.2, R39.2, R40.2, R41.2, R42.2, R43.2, R44.2, R45.2, R46.2, R47.2, R48.2, R49.2, R50.2, R51.2, R52.2, R53.2, R54.2, R55.2, R56.2, R57.2, R58.2, R59.2, R60.2, R61.2, R62.2, R63.2, R64.2, R65.2, R66.2, R67.2, R68.2, R69.2, R70.2, R71.2, R72.2, R73.2, R74.2, R75.2, R76.2, R77.2, R78.2, R79.2, R80.2, R81.2, R82.2, R83.2, R84.2, R85.2, R86.2, R87.2, U1.40

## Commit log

2021-08-04 ダイオードを直列から並列に変更
    [KiCAD.kicad_pcb, KiCAD.sch]
2021-08-05 テンキーを消した。キー軸の上下を逆にした。マイコンを一つ無くした。デバッグ用LEDを無くした。結果PCBnewを作り直すことになった。
    [KiCAD.kicad_pcb, KiCAD.sch]
2021-08-06 グローバルラベルにした。
    [KiCAD.sch]
2021-08-16 フットプリントを変えた。
    [KiCAD.kicad_pcb, KiCAD.sch]
2021-08-17 フットプリント配置中
    [KiCAD.kicad_pcb]
2021-08-17 改変フットプリントを追加
2021-08-17 キーキャップの寸法を確定させないと何も設計できない
    [KiCAD.kicad_pcb, KiCAD.sch]
2021-08-18 Push できる？
    [KiCAD.kicad_pcb]
2021-08-18 PDF を追加
    [KiCAD.kicad_pcb, KiCAD.sch]
2021-08-26 ツリー構造を変更した
    [KiCAD.kicad_pcb, KiCAD.sch]
2021-09-01 Ƃ肠¦¸®¬I
    [KiCAD.kicad_pcb, KiCAD.sch]
2021-09-01 とりあえず完成
    [KiCAD.kicad_pcb, KiCAD.sch]
2021-09-02 add gerber data
    [KiCAD.kicad_pcb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]
2021-09-02 add gerber data and change file tree
    [keyboard_h.drl, keyboard_h.gbl, keyboard_h.gbo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]
2021-09-05 LED の点灯方法を変更。それぞれの LED に電流制限抵抗を追加。
    [KiCAD.kicad_pcb, KiCAD.sch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]
2021-09-05 シャーシ設計用に 3D モデルだけ出力できるようにもう一つ KiCAD プロジェクトを作った。まだラズパイピコのモデルデータを実装できてない。
    [keyboard_h.kicad_pcb, keyboard_h.sch]
2021-09-05 step ファイルを出力した
    [keyboard_h.kicad_pcb, keyboard_h.sch]
2021-09-06 Mount Hall の位置を調節した。3D モデルには手を着けてないから使えないよ！
    [KiCAD.kicad_pcb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]
2021-09-06 Inventor で Plate を作った。
    [Plate.0006.ipt, Plate.ipt, Plate.stp]
2021-09-08 GS間抵抗を追加。G抵抗を追加。なんかスイッチのフットプリント一つ消えちゃった
    [KiCAD.kicad_pcb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]
2021-09-08 復元した
    [KiCAD.sch]
2021-09-09 これからアンテナに気を付けつつベタグランドを追加する
    [KiCAD.kicad_pcb]
2021-09-09 とりあえず配線幅を太くした。
    [KiCAD.kicad_pcb]
2021-09-09 配線の横に流れる電流値を記載しておいた。
    [KiCAD.kicad_pcb]
2021-09-09 ベタグランドの配置途中
    [KiCAD.kicad_pcb]
2021-09-11 x^Oh̃Aei𖳂­µ½Bzüð0.3mm ɂµ½B
    [KiCAD.kicad_pcb]
2021-09-12 Plate に支柱を付けた
    [Plate.0006.ipt, Plate.0007.ipt, Plate.ipt]
2021-09-12 これなにした？
    [KiCAD.kicad_pcb]
2021-09-12 step ファイルの追加
    [KiCAD.kicad_pcb, KiCAD.sch, keyboard_h.kicad_pcb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]
2021-09-12 3D モデルの正投影 PNG を追加
2021-09-14 Plate を少し広くした
    [Plate.0007.ipt, Plate.0010.ipt, Plate.step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]
2021-09-14 とりあえず自分なりにベタグランドのアンテナを除去した
    [KiCAD.kicad_pcb]
2021-09-14 ベタグランドのアンテナを除去してデザインルールチェックも済ませた.
    [KiCAD.kicad_pcb]
2021-09-14 ガーバファイルまで出力
    [keyboard_h.GKO, keyboard_h.gbl, keyboard_h.gbo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]
2021-09-16 2u キーにスタビライザを適応
    [KiCAD.kicad_pcb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]
2021-09-21 Inventor バージョンに配慮
    [Plate.0010.ipt, Plate.idw, Plate.step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]
2021-09-21 Base を作成
    [Base.x_t, Plate.0001.idw, Plate.idw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]
2021-09-22 Inventor Board の作成
    [Base.0012.ipt, Base.idw, Base.ipt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]
2021-09-24 人に見せる用のファイルを追加
    [KiCAD.kicad_pcb, circuit.kicad_pcb, circuit.sch]
2021-09-24 PDF データでええやんってなった。
    [circuit.kicad_pcb]
2021-09-25 ピンヘッダno
    [PinHeader_1x20_P2.54mm_Horizontal.step, keyboard_h.kicad_pcb]
2021-09-25 ピンヘッダの STEP ファイルを追加
    [PinHeader_1x20_P2.54mm_Horizontal.step, PinHeader_1x20_P2.54mm_Vertical.step]
2021-09-25 まだねじ穴斬ってない
    [Assembly.0004.iam, Assembly.iam, Base.0001.idw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]
2021-09-30 MISUMI で注文できるように調整。MC で削りだせるように調整
    [Assembly.0004.iam, Assembly.0012.iam, Assembly.iam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]
2021-11-20 Base の微調整
    [Assembly.0012.iam, Assembly.0013.iam, Assembly.iam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]
2021-11-20 重大な修正 基板との干渉を解消
    [Plate.0039.ipt, Plate.0040.ipt, Plate.ipt]

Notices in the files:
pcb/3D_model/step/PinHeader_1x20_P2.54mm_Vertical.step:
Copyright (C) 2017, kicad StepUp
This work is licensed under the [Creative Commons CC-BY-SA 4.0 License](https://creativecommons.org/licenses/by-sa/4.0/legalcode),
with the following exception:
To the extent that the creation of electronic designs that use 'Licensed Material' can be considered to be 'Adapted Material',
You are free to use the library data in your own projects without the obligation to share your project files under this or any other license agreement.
